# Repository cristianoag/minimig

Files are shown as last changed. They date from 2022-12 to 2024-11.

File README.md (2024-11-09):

# minimig
Recreating an Amiga500 with FPGA (consolidated repository)

The Minimig (short for "Mini Amiga") is a remarkable open-source hardware project designed to replicate the beloved Amiga 500 home computer, an iconic system from the late 1980s and early 1990s. Conceived by enthusiast Dennis van Weeren in 2005, the Minimig project began as a labor of love to faithfully recreate the Amiga’s unique architecture on an FPGA (Field Programmable Gate Array). Over time, it evolved with community contributions and open-source improvements, resulting in a versatile, accessible, and compact recreation of the original Amiga 500 that enthusiasts worldwide could use to relive and preserve classic Amiga software and games.

## Motivation
Recently I've been busy building a Minimig board. The Minimig is an FPGA-based implementation of the original Commodore Amiga 500 hardware.

This repository, together with the document available at http://www.theretrohacker.com/2022/12/20/an-fppga-based-amiga-the-minimig/ is my attempt to consolidate the very disperse documentation about the minimig and offer a concise guide if you want to build a board. Most of the websites that hosted files required are also offline currently. 

## License 

Open Hardware

This work is licensed under a [Creative Commons Attribution-NonCommercial-ShareAlike 4.0 International License](http://creativecommons.org/licenses/by-nc-sa/4.0/).

* If you remix, transform, or build upon the material, you must distribute your contributions under the same license as the original.
* You may not use the material for commercial purposes.
* You must give appropriate credit, provide a link to the license, and indicate if changes were made. You may do so in any reasonable manner, but not in any way that suggests the licensor endorses you or your use.

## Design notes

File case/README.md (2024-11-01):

# minimig cases

This folder stores multiple options for the minimig case. 

* 3D - Cases to be printed on 3D printers, also combined with acrylic top covers
* Acrylic - Full acrylic options to be cut on laser CNCs.

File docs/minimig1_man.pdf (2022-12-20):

## Minimig manual

Introduction
Well, you have built a Minimig board! Congratulations! This board should be considered purely experimental and is not a finished product. Therefore, some functions may not work and compatibility is not as good as a real Amiga. Also, be especially careful with ESD (electro static discharge). Although some protection is built into the Minimig, ESD can still kill it. This short manual will get you going with your Minimig. Please read it through carefully. I hope you will enjoy using the Minimig!

Configuring the flash card
To get the Minimig started, a FAT16-formatted MMC card is needed. A compatible card is supplied with the board. This card must contain at least the following files in the root directory:
- MINIMIG1.BIN
This is the FPGA core file needed to correctly configure the Spartan FPGA
- KICK.ROM
This is the kickstart rom file. All kickstart versions are supported but versions 1.2 or 1.3 are recommended for game compatibility.
Besides these two files, some ADF files are needed to let the Minimig do something more than displaying the Amiga boot screen. All files must be in the root directory. Sub directories are not supported.

Hooking up the Minimig
- Power
The Minimig must be supplied with a 5V STABILIZED POWER SUPPLY. Please use only the supplied power supply. A power supply with the wrong voltage or polarity will certainly damage the Minimig. Connect the power supply to the 2.1mm jack labelled “DC IN” at the back of the board. Centre pin is positive.
- Monitor
The Minimig has a standard 15pin VGA connector labelled “video” at the back of the board. Any monitor capable of displaying 50Hz display modes can be used. The 3-pin jumper next to this connector must be set to 31KHz (default).
- Audio
Standard PC-speakers can be connected to the 3.5mm jack labelled “audio” at the back of the board.
- Keyboard
A standard PS2 keyboard must be connected to the 6-pin mini connector labelled “keyboard” on the left-hand side of the board. A keyboard is necessary to operate the Minimig on-screen-display and to load ADF files. Some older keyboards may not work on the Minimig.
- Mouse
A standard PS2 mouse must be connected to the 6-pin mini connector labelled “mouse” on the left-hand side of the board. An optical mouse is supported.
- Joysticks
The Minimig has 2 9-pin joystick ports at the right-hand side of the board. Standard Amiga joysticks can be connected to these ports. The standard port for single-player games is the “JOY2” (upper) port. Do not use the 9-pin port at the back, that port is a serial port!

Powering up
Before applying power to Minimig, insert the MMC card. The card is only recognized at powerup. After applying power, the blue led (system power) will light up. The Minimig will search for the “minimig1.bin” and “kick.rom” files to boot the system. This may take a few moments. The loading of the kickstart rom will flash the screen in true retro-decrunching-style. This is normal behaviour. When the system has booted completely, the familiar Amiga boot screen will be shown.

On-screen-display
The Minimig is now ready for use and can be operated using 4 special keys on the PS2 keyboard and a so-called on-screen-display. The keys used are:
- F12
Just as with UAE, this key will invoke the on-screen-display. Pressing F12 again will hide the on-screen-display. The on-screendisplay can also be invoked by pressing the menu button at the front of the Minimig board.
- Page-up / Page-down
These keys are used to navigate the on-screen-display up and down.
- Home
This key is used to select an item on the on-screen-display.
The operating of the on-screen-display should be self-explanatory .

Resetting the Minimig
Just as with AOS 4.0, the Minimig is reset by holding down the control, left alt and right alt keys simultaneously. This will only reset the Amiga-side of the system. To reset the system completely or to reload the MMC-card, the power must be switched off/on.

More information
For more information, point your browser to http://home.hetnet.nl/~weeren001.

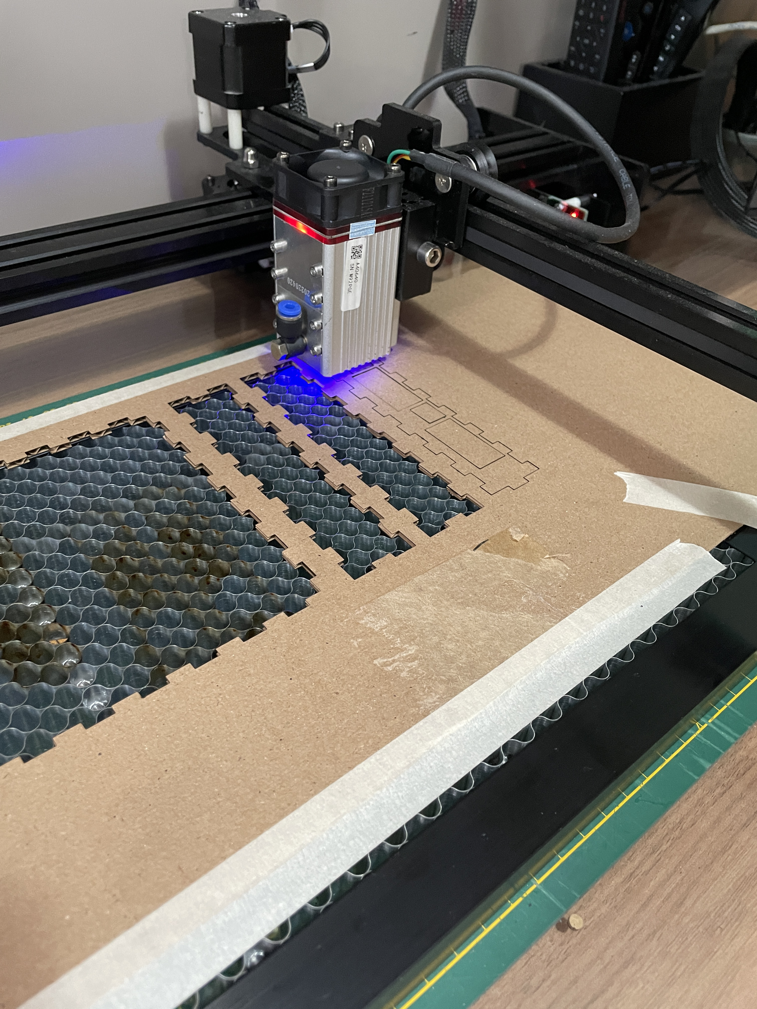
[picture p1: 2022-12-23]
pictures/20221222_165639893_iOS.jpg

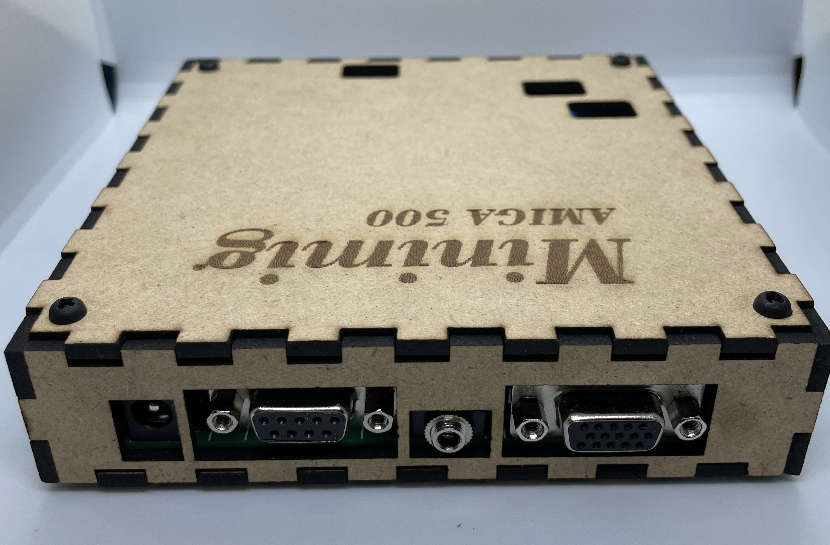
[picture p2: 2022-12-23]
pictures/20221222_223855441_iOS.jpg

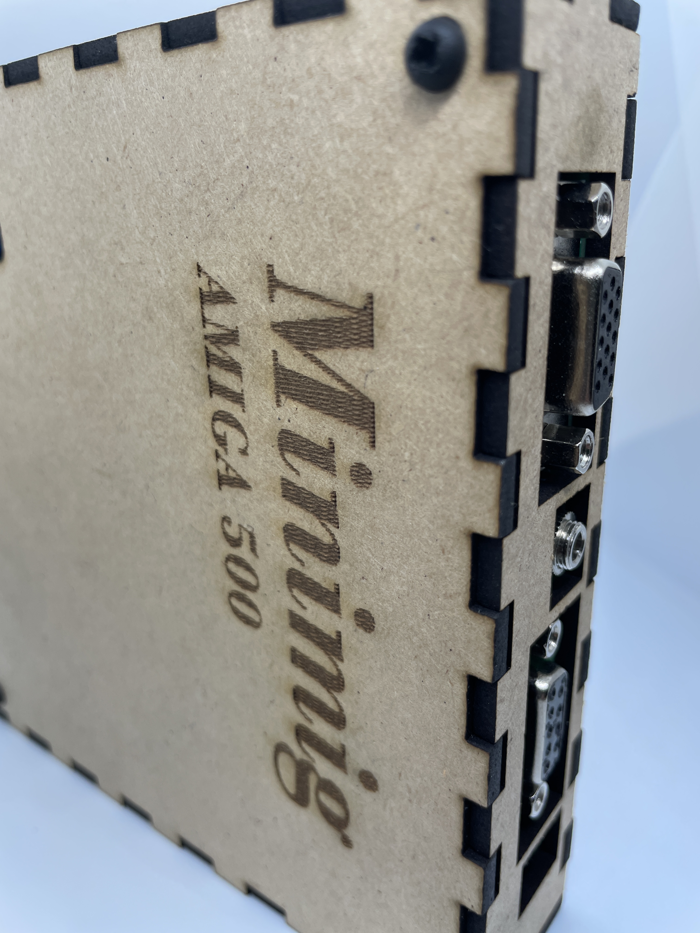
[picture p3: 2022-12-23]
pictures/20221222_223939605_iOS.jpg

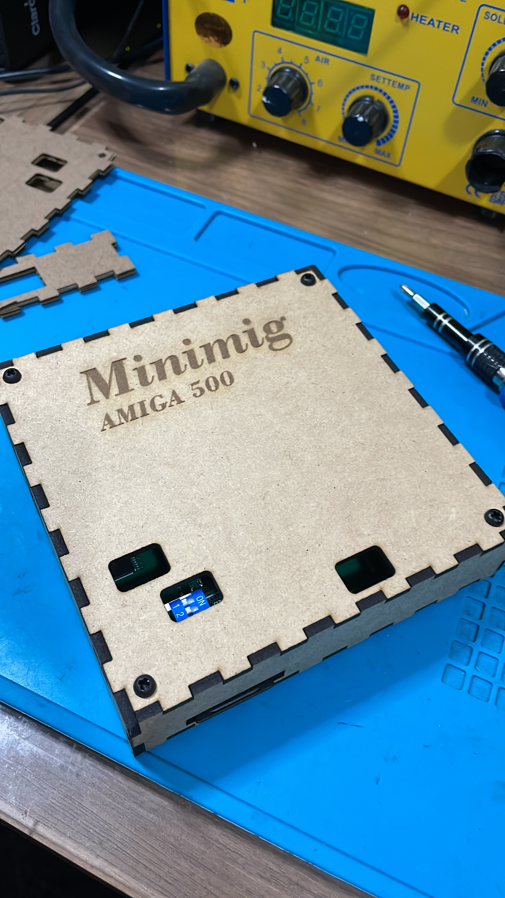
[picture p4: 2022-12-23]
pictures/20221222_202334973_iOS.jpg

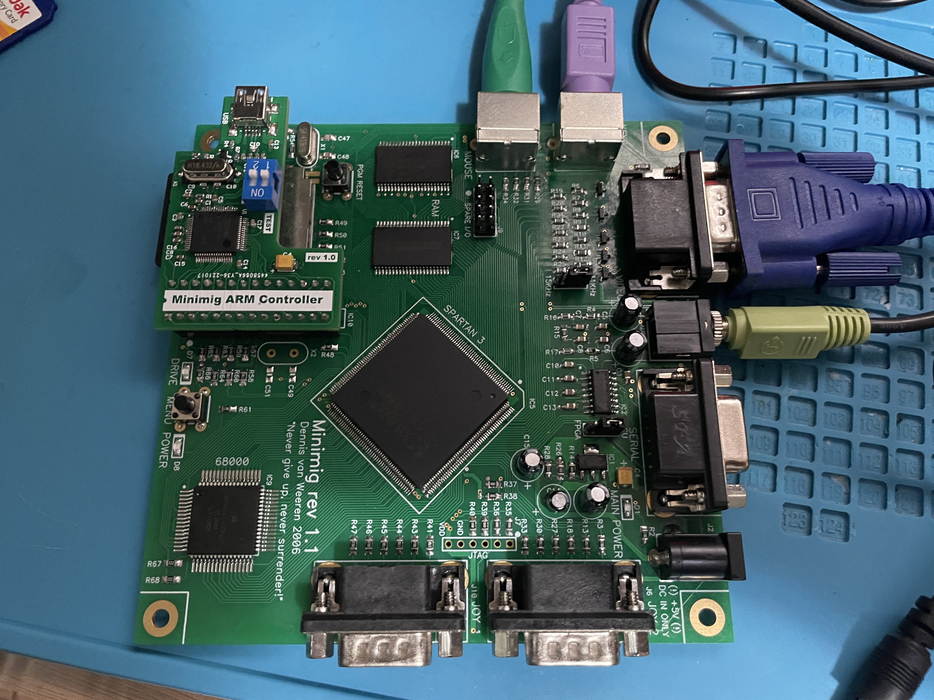
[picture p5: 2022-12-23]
pictures/20221220_040915800_iOS.jpg

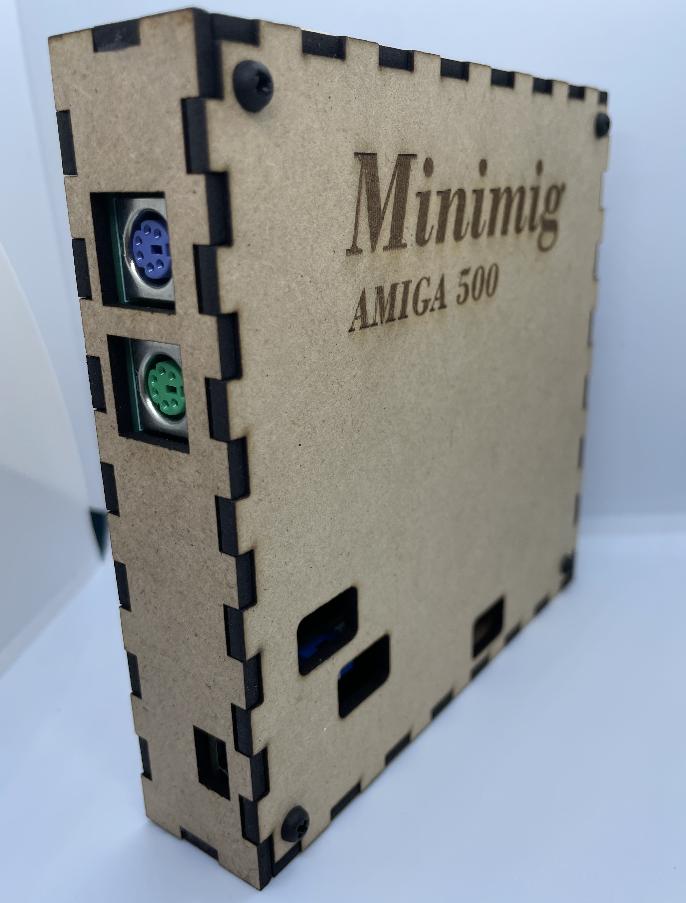
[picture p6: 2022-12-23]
pictures/20221222_223845031_iOS.jpg

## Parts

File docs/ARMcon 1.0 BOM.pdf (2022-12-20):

### Minimig ARM Controller 1.0 BOM

Value | Designator | Parameters | Manufacturer | Quantity
27R | R2, R3 | 0603 27R 0.1W 1% | | 2
1K5 | R1, R7 | 0603 1K5 0.1W 1% | | 2
10K | R6 | 0603 10K 0.1W 1% | | 1
100K | R5 | 0603 100K 0.1W 1% | | 1
1M | R4 | 0603 1M 0.1W 5% | | 1
10p | C9, C18 | 0603 10pF 50V 5% C0G | | 2
15p | C11, C12 | 0603 15pF 50V 5% C0G | | 2
33p | C10 | 0603 33pF 50V 5% C0G | | 1
1n | C1, C5, C8, C13 | 0603 1nF 50V 5% C0G | | 4
10n | C2 | 0603 10nF 50V 10% X7R | | 1
100n | C3, C14, C15, C16, C17 | 0603 100nF 16V 10% X7R | | 5
1u | C6, C7 | 0603 1uF 6.3V 10% X7R | | 2
10u/16V | C4 | SMD-B 10uF 10% 16V Tantalum | | 1
BC807-25 | Q1 | BC807-25 | NXP | 1
AT91SAM7S256-AU-001 | U1 | AT91SAM7S256-AU-001 | Atmel | 1
18.432MHz | X1 | HC49/SM 18.432 MHz | | 1
USB | CN1 | USB mini-B 5-pin SMD | | 1
28-pin header | U2 | 2 x 14-Pin Gold SIL Connector | preci-dip | 1

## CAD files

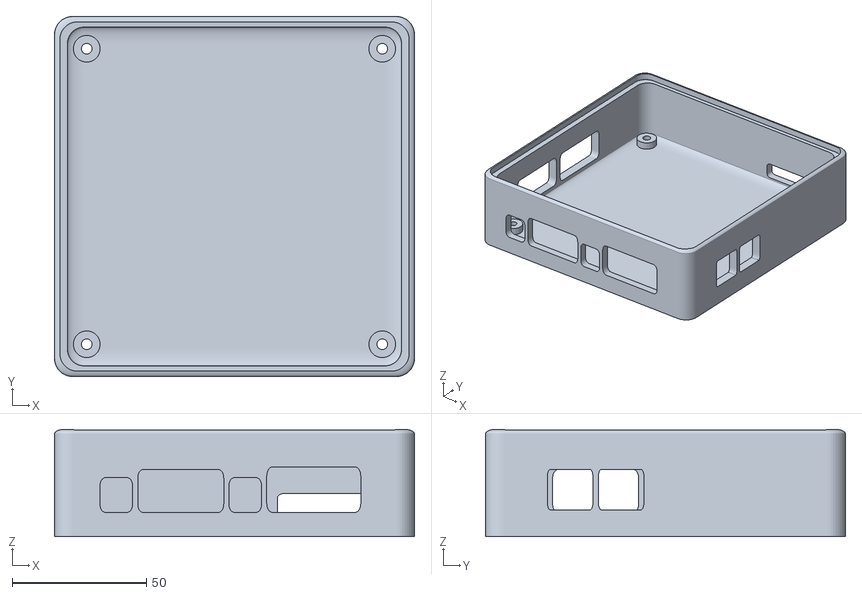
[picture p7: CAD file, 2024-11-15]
case/3D/Minimig Case [1.1].stl
134.0 x 134.0 x 39.9

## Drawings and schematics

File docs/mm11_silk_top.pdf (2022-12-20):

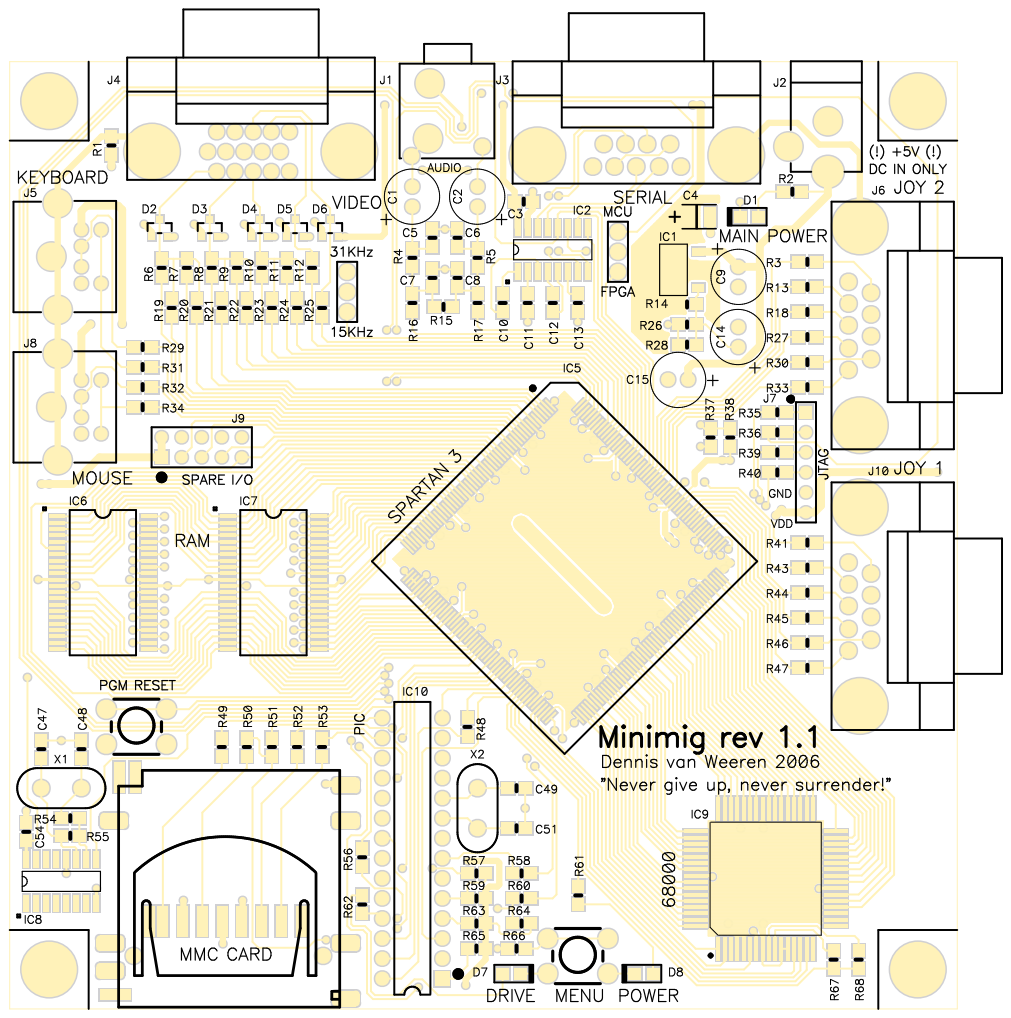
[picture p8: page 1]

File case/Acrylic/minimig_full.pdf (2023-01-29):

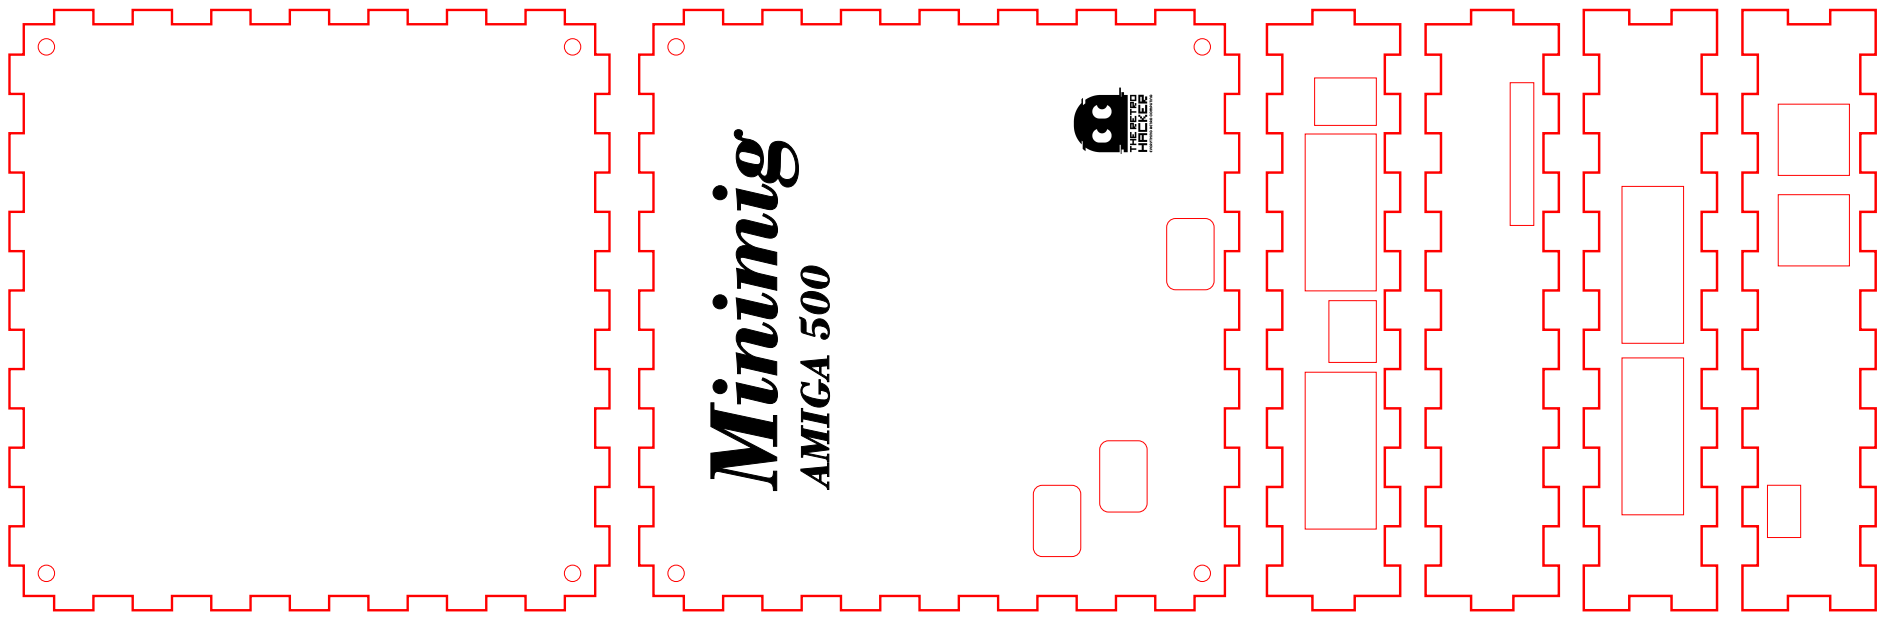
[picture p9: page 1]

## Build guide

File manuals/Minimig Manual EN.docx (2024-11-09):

# Minimig Manual – 1.0

## Introduction

The Minimig (short for "Mini Amiga") is a remarkable open-source hardware project designed to replicate the beloved Amiga 500 home computer, an iconic system from the late 1980s and early 1990s. Conceived by enthusiast Dennis van Weeren in 2005, the Minimig project began as a labor of love to faithfully recreate the Amiga’s unique architecture on an FPGA (Field Programmable Gate Array). Over time, it evolved with community contributions and open-source improvements, resulting in a versatile, accessible, and compact recreation of the original Amiga 500 that enthusiasts worldwide could use to relive and preserve classic Amiga software and games.

The Amiga series was revolutionary in its day, offering groundbreaking graphics, multitasking, and sound capabilities. However, as the years passed, finding original Amiga hardware became challenging. The Minimig emerged as a solution, delivering the authentic Amiga experience without the pitfalls of aging components.

The open-source design allows users and developers to continuously improve and expand its capabilities, making it both a practical choice and a nod to the pioneering spirit of the Amiga.

The Minimig you hold is designed for ease of use and portability, making it simple to run Amiga applications on modern hardware while capturing the nostalgia and ingenuity of the original machine. This manual will guide you through the setup and essential functions, helping you start your journey with the Minimig confidently and safely.

A Note on ESD (Electrostatic Discharge): Like any sensitive electronic equipment, the Minimig is susceptible to electrostatic discharge. While some ESD protection is built in, please take precautions to avoid direct static contact with the device.

This short manual will get you going with your Minimig, covering essential steps and tips to enhance your experience. Please read it carefully, and I hope you enjoy this modern take on a classic piece of computing history.

## Configuring the SD card

To get your Minimig started, you’ll need a FAT32-formatted SD card to store the essential files and software. A compatible SD card is provided with your Minimig, preformatted and ready to go. The root directory of this card must contain at least the following core files:

- MINIMIG1.BIN - This is the FPGA core file that allows the Minimig to initialize and configure the Spartan FPGA, essentially loading the hardware design that replicates the Amiga system. Without this file, the Minimig cannot properly start up.
- KICK.ROM - This is the Kickstart ROM file, which serves as the initial loading ROM for the Amiga environment. The Minimig supports various versions of the Kickstart ROM, including Kickstart 1.3, 2.0, and 3.1. Each version provides compatibility with different Amiga software, so feel free to experiment with the ROM version that best suits your needs. You can purchase the official/legal Amiga Kickstart at https://www.amigaforever.com/value/

In addition to these two core files, you’ll want to load some ADF (Amiga Disk Format) files onto the SD card. These files act as virtual disks containing games, software, or utilities in the original Amiga format. With ADF files on your SD card, the Minimig can go beyond displaying the basic Amiga boot screen and provide access to the full range of Amiga applications and games.

Since the Minimig you hold is equipped with an advanced ARM controller, the SD card supports folders, allowing you to organize your software collection neatly. You can create folders for different categories, such as “Games,” “Demos,” or “Utilities,” making it easier to locate and load specific applications.

Also observe the following tips when configuring your Minimig SD card:

1. File Compatibility: Ensure that the MINIMIG1.BIN and KICK.ROM files are compatible with your Minimig version. Regularly check the Minimig community for updates, as new FPGA core files and Kickstart compatibility enhancements are periodically released.
2. Organizing ADF Files: If your SD card contains a large collection of ADF files, using subfolders will improve navigation. The ARM controller on the Minimig allows you to browse and load ADF files from different folders through the on-screen menu, streamlining your experience.
3. Back Up Your SD Card: Before making significant changes, such as updating core files or adding many ADFs, it’s a good practice to back up the contents of your SD card. This ensures you can restore the system if needed.

With the SD card correctly set up, your Minimig is ready to launch into the Amiga experience. Make sure to insert the card into the Minimig’s SD slot securely before powering it on and enjoy exploring the digital heritage of the Amiga on your modern hardware.

## Hooking up the Minimig

To set up your Minimig, you’ll need to connect several peripherals to ensure proper operation. Follow these instructions carefully to prevent damage and get the best experience from your Minimig.

- Power - The Minimig requires a 5V 2A stabilized power supply to function safely. Only use the power supply provided with the Minimig, as power supplies with incorrect voltage or polarity may damage the system irreparably. Insert the power supply’s connector into the 2.1mm jack labeled “DC IN” at the back of the board, ensuring the center pin is positive.
- Monitor - The Minimig includes a standard 15-pin VGA connector labeled “VIDEO” at the back. You can use most modern monitors capable of displaying 50Hz video modes. Next to the VGA connector, you’ll find a 3-pin jumper that should be set to 31KHz (default), allowing compatibility with most VGA monitors. For compatibility with 15KHz monitors (such as certain vintage monitors), adjust the jumper to the 15KHz setting. Note that 15KHz monitors are uncommon, so be sure to check your monitor’s specifications if you intend to use one.
- Audio - To enjoy audio output, connect speakers or headphones to the 3.5mm audio jack labeled “AUDIO” at the back of the board. This provides stereo sound output, recreating the distinctive audio experience of the original Amiga system.
- Keyboard - A PS/2 keyboard is required for navigating the Minimig on-screen display (OSD) and loading ADF files. Connect the keyboard to the 6-pin mini-DIN connector labeled “KEYBOARD” on the left side of the board.
- Mouse - To interact with Amiga software effectively, a PS/2 mouse is recommended. The mouse connects to the 6-pin mini-DIN connector labeled “MOUSE” on the left side of the board. Optical mice are supported, though compatibility may vary depending on the model. The mouse is essential for Amiga software, which often relies heavily on pointer-based navigation.
- Joysticks - The Minimig supports two standard 9-pin Amiga joysticks, connectable via ports located on the right side of the board. The “JOY2” (upper) port is typically used as the primary joystick port for single-player games, while the “JOY1” (lower) port can be used for multiplayer games or other applications.

Note: Avoid connecting joysticks to the 9-pin port on the back of the board, as this is a serial port (female connector) and not intended for joystick use.

Following these set-up instructions will prepare your Minimig for operation, allowing you to enjoy a seamless experience as you explore Amiga software and games.

## Powering up

Before powering on your Minimig, insert the preconfigured SD card into the MMC slot. The Minimig can only recognize the SD card at startup, so ensure it’s inserted before applying power.

- Power On - Once the SD card is securely in place, connect the power supply to the Minimig. When powered on, the blue LED (system power indicator) will illuminate, signaling that the system is receiving power and initializing.
- File Loading - The Minimig will immediately begin searching for the SD card’s root directory for the MINIMIG1.BIN and KICK.ROM files, essential for the system to boot. The FPGA core (MINIMIG1.BIN) configures the FPGA hardware to run the Amiga hardware, while the KICK.ROM file loads the Amiga’s boot ROM.
- Kickstart ROM Initialization - As the Kickstart ROM loads, you may notice the screen flashing—a nostalgic “decrunching” effect reminiscent of the original Amiga boot process. This is normal behavior and indicates that the Minimig is initializing components and setting up the Amiga environment.
- Amiga Boot Screen - After the ROM has fully loaded, the familiar Amiga boot screen will appear. If ADF files are present on the SD card, you’ll be able to load them from the on-screen display (OSD) using your keyboard. At this stage, the Minimig is fully operational and ready to run Amiga software.

Once the boot process is complete, enjoy exploring your favorite Amiga applications and games, all faithfully recreated on your Minimig!

## Loading ADF Files Using the On-Screen Display (OSD)

With the Minimig booted up, you’re ready to load Amiga Disk Format (ADF) files—virtual disk images that allow you to run Amiga games and applications. The process of loading ADF files is managed through the on-screen display (OSD), which can be easily accessed using specific keys on your PS/2 keyboard.

The following keys are dedicated to navigating the OSD and loading ADF files:

- F12 Key - Press the F12 key to activate the on-screen display. This key works similarly to the UAE emulator, instantly bringing up the OSD. Pressing F12 again will close the OSD, returning you to the Amiga environment. Alternatively, you can also invoke the OSD by pressing the Menu button located at the front of the Minimig board.
- Page Up / Page Down Keys - Use the Page Up and Page Down keys to scroll through the options within the OSD. This allows you to browse folders, navigate specific ADF files, and access various settings on the Minimig.

Follow the steps below to load ADF files:

1. Access the OSD - Press F12 (or the Menu button on the Minimig) to bring up the OSD.
2. Navigate to the ADF File - Use Page Up and Page Down to scroll through the file list on the SD card. If you have organized your files into folders (e.g., “Games” or “Demos”), navigate to the desired folder.
3. Select an ADF File - Once you locate the ADF file you want to load, press space or enter key to select it. This will mount the ADF file as a virtual disk in the Amiga environment.
4. Start the Application - After selecting an ADF file, exit the OSD by pressing F12 again. The Minimig will automatically begin reading the selected ADF file, and the corresponding Amiga application or game should start shortly.

### Additional Tips

- Swapping Disks: For multi-disk games or applications, use the OSD to load additional ADF files as needed. Simply reopen the OSD, navigate to the next disk image, and select it with the Home key. Many games prompt you when to insert the next disk.
- Settings and Configurations: Besides loading ADF files, the OSD also allows you to configure various system settings, such as display modes and audio options. These can be adjusted through the OSD to customize your experience.

The on-screen display is intuitive, giving you quick and easy control over the Minimig functions. Once you’re comfortable with the OSD, loading and switching ADF files becomes a seamless part of the Amiga experience.

## Resetting the Minimig

Just as with AOS 4.0, the Minimig is reset by holding down the control, left alt and right alt keys simultaneously. This will only reset the Amiga-side of the system. To reset the system completely or to reload the MMC-card, the power must be switched off/on.

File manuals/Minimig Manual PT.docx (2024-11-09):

# Manual Minimig – 1.0

## Introdução

O Minimig (abreviação de "Mini Amiga") é um notável projeto de hardware de código aberto projetado para replicar o amado computador doméstico Amiga 500, um sistema icônico do final dos anos 1980 e início dos anos 1990.

Concebido pelo entusiasta Dennis van Weeren em 2005, o projeto Minimig começou como um trabalho de para recriar fielmente a arquitetura única do Amiga em um FPGA (Field Programmable Gate Array). Com o tempo, ele evoluiu com contribuições da comunidade e melhorias de código aberto, resultando em uma recriação versátil, acessível e compacta do Amiga 500 original que os entusiastas de todo o mundo poderiam usar para reviver e preservar o software e os jogos clássicos do Amiga.

A série Amiga foi revolucionária em sua época, oferecendo gráficos inovadores, multitarefa e recursos de som. No entanto, com o passar dos anos, encontrar o hardware original do Amiga tornou-se um desafio. O Minimig surgiu como uma solução, oferecendo a autêntica experiência do Amiga sem as armadilhas dos componentes antigos.

O design de código aberto permite que usuários e desenvolvedores melhorem e expandam continuamente seus recursos, tornando-o uma escolha prática e um aceno para o espírito pioneiro do Amiga.

O Minimig que você possui foi projetado para facilidade de uso e portabilidade, simplificando a execução de aplicativos Amiga em hardware moderno, capturando a nostalgia e a engenhosidade da máquina original. Este manual irá guiá-lo através da configuração e das funções essenciais, ajudando você a iniciar sua jornada com o Minimig com confiança e segurança.

Uma nota sobre ESD (descarga eletrostática): Como qualquer equipamento eletrônico sensível, o Minimig é suscetível a descargas eletrostáticas. Embora alguma proteção ESD esteja integrada, tome precauções para evitar o contato estático direto com o dispositivo.

Este pequeno manual irá ajudá-lo a usar seu Minimig, cobrindo etapas e dicas essenciais para aprimorar sua experiência. Por favor, leia-o com atenção e espero que você goste desta versão moderna de uma peça clássica da história da computação.

## Configurando o cartão SD

Para iniciar seu Minimig, você precisará de um cartão SD formatado em FAT32 para armazenar os arquivos e softwares essenciais. Um cartão SD compatível é fornecido com seu Minimig, pré-formatado e pronto para uso. O diretório raiz desta placa deve conter pelo menos os seguintes arquivos principais:

1. MINIMIG1. BIN - Este é o arquivo principal do FPGA que permite que o Minimig inicialize e configure o FPGA Spartan, essencialmente carregando o design de hardware que replica o sistema Amiga. Sem esse arquivo, o Minimig não pode iniciar corretamente.
2. KICK. ROM - Este é o arquivo ROM do Kickstart, que serve como ROM de carga inicial para o ambiente Amiga. O Minimig suporta várias versões da ROM do Kickstart, incluindo Kickstart 1.3, 2.0 e 3.1. Cada versão oferece compatibilidade com diferentes softwares Amiga, portanto, sinta-se à vontade para experimentar a versão da ROM que melhor se adapta às suas necessidades. Você pode comprar o Amiga Kickstart oficial/legal em https://www.amigaforever.com/value/

Além desses dois arquivos principais, você deve carregar alguns arquivos ADF (Amiga Disk Format) no cartão SD. Esses arquivos atuam como discos virtuais contendo jogos, software ou utilitários no formato original do Amiga. Com arquivos ADF em seu cartão SD, o Minimig pode ir além de exibir a tela básica de inicialização do Amiga e fornecer acesso a toda a gama de aplicativos e jogos do Amiga.

Como o Minimig que você possui está equipado com um controlador ARM avançado, o cartão SD suporta pastas, permitindo que você organize sua coleção de software de maneira organizada. Você pode criar pastas para diferentes categorias, como "Jogos", "Demos" ou "Utilitários", facilitando a localização e o carregamento de aplicativos específicos.

Observe também as seguintes dicas ao configurar seu cartão SD Minimig:

1. Compatibilidade de arquivos: Certifique-se de que o MINIMIG1. BIN e KICK.ROM são compatíveis com sua versão do Minimig. Verifique regularmente a comunidade Minimig para atualizações, pois novos arquivos principais do FPGA e aprimoramentos de compatibilidade do Kickstart são lançados periodicamente.
2. Organizando arquivos ADF: Se o seu cartão SD contiver uma grande coleção de arquivos ADF, o uso de subpastas melhorará a navegação. O controlador ARM no Minimig permite que você navegue e carregue arquivos ADF de diferentes pastas através do menu na tela, agilizando sua experiência.
3. Faça backup do seu cartão SD – Antes de fazer alterações significativas, como atualizar arquivos principais ou adicionar muitos ADFs, é uma boa prática fazer backup do conteúdo do seu cartão SD. Isso garante que você possa restaurar o sistema, se necessário.

Com o cartão SD configurado corretamente, seu Minimig está pronto para iniciar a experiência do Amiga. Certifique-se de inserir o cartão no slot SD do Minimig com segurança antes de ligá-lo e aproveite para explorar a herança digital do Amiga em seu hardware moderno.

## Conectando o Minimig

Para configurar seu Minimig, você precisará conectar vários periféricos para garantir o funcionamento adequado. Siga estas instruções cuidadosamente para evitar danos e obter a melhor experiência do seu Minimig.

1. Energia - O Minimig requer uma fonte de alimentação estabilizada de 5V 2A para funcionar com segurança. Utilize apenas a fonte de alimentação fornecida com o Minimig, pois fontes de alimentação com tensão ou polaridade incorretas podem danificar o sistema de forma irreparável. Insira o conector da fonte de alimentação no conector de 2.1 mm identificado como "DC IN" na parte traseira da placa, garantindo que o pino central seja positivo.
2. Monitor - O Minimig inclui um conector VGA padrão de 15 pinos rotulado como "VIDEO" na parte traseira. Você pode usar a maioria dos monitores modernos capazes de exibir modos de vídeo de 50Hz vertical. Ao lado do conector VGA, você encontrará um jumper de 3 pinos que deve ser definido como 31KHz (padrão), permitindo compatibilidade com a maioria dos monitores VGA. Para compatibilidade com monitores de 15KHz (como certos monitores antigos), ajuste o jumper para a configuração de 15KHz. Observe que os monitores de 15KHz são incomuns, portanto, verifique as especificações do seu monitor se pretende usar um.
3. Áudio - Para aproveitar a saída de áudio, conecte alto-falantes ou fones de ouvido ao conector de áudio de 3,5 mm identificado como "AUDIO" na parte traseira da placa. Isso fornece saída de som estéreo, recriando a experiência de áudio distinta do sistema Amiga original.
4. Teclado - Um teclado PS/2 é necessário para navegar na exibição na tela (OSD) do Minimig e carregar arquivos ADF. Conecte o teclado ao conector mini-DIN de 6 pinos identificado como "KEYBOARD" no lado esquerdo da placa.
5. Mouse - Para interagir com o software Amiga de forma eficaz, recomenda-se um mouse PS/2. O mouse se conecta ao conector mini-DIN de 6 pinos identificado como "MOUSE" no lado esquerdo da placa. Mouses ópticos são suportados, embora a compatibilidade possa variar dependendo do modelo. O mouse é essencial para o software Amiga, que geralmente depende muito da navegação baseada em ponteiros.
6. Joysticks - O Minimig suporta dois joysticks Amiga padrão de 9 pinos, conectáveis através de portas localizadas no lado direito da placa. A porta "JOY2" (superior) é normalmente usada como a porta principal do joystick para jogos single-player, enquanto a porta "JOY1" (inferior) pode ser usada para jogos multiplayer ou outros aplicativos.

Observação: evite conectar joysticks à porta de 9 pinos na parte traseira da placa, pois esta é uma porta serial (conector fêmea) e não se destina ao uso de joystick.

Seguir estas instruções de configuração preparará seu Minimig para operação, permitindo que você desfrute de uma experiência perfeita enquanto explora o software e os jogos do Amiga.

## Ligando o computador

Antes de ligar o Minimig, insira o cartão SD pré-configurado no slot MMC. O Minimig só pode reconhecer o cartão SD na inicialização, portanto, certifique-se de que ele esteja inserido antes de ligar a energia.

1. Ligar - Assim que o cartão SD estiver firmemente no lugar, conecte a fonte de alimentação ao Minimig. Quando ligado, o LED azul (indicador de energia do sistema) acenderá, sinalizando que o sistema está recebendo energia e inicializando.
2. Carregamento de arquivos - O Minimig começará imediatamente a procurar o diretório raiz do cartão SD para o MINIMIG1. BIN e KICK. ROM, essenciais para a inicialização do sistema. O núcleo FPGA (MINIMIG1. BIN) configura o hardware FPGA para executar o hardware Amiga, enquanto o KICK. ROM carrega a ROM de inicialização do Amiga.
3. Inicialização da ROM do Kickstart - À medida que a ROM do Kickstart é carregada, você pode notar a tela piscando - um efeito nostálgico de "decrunching" que lembra o processo de inicialização original do Amiga. Este é um comportamento normal e indica que o Minimig está inicializando componentes e configurando o ambiente do Amiga.
4. Tela de inicialização do Amiga - Depois que a ROM for totalmente carregada, a tela de inicialização familiar do Amiga aparecerá. Se os arquivos ADF estiverem presentes no cartão SD, você poderá carregá-los na exibição na tela (OSD) usando o teclado. Nesta fase, o Minimig está totalmente operacional e pronto para rodar o software Amiga.

Assim que o processo de inicialização estiver concluído, divirta-se explorando seus aplicativos e jogos favoritos do Amiga, todos fielmente recriados em seu Minimig!

## Carregando arquivos do ADF usando a exibição na tela (OSD)

Com o Minimig inicializado, você está pronto para carregar arquivos Amiga Disk Format (ADF) - imagens de disco virtual que permitem executar jogos e aplicativos do Amiga. O processo de carregamento de arquivos ADF é gerenciado por meio da exibição na tela (OSD), que pode ser facilmente acessada usando teclas específicas em seu teclado PS/2.

As seguintes teclas são dedicadas à navegação no OSD e ao carregamento de arquivos ADF:

1. Tecla F12 - Pressione a tecla F12 para ativar a exibição na tela. Essa chave funciona de forma semelhante ao emulador dos Emirados Árabes Unidos, ativando instantaneamente o OSD. Pressionar F12 novamente fechará o OSD, retornando ao ambiente Amiga. Como alternativa, você também pode invocar o OSD pressionando o botão Menu localizado na frente da placa Minimig.
2. Teclas Page Up / Page Down - Use as teclas Page Up e Page Down para percorrer as opções no OSD. Isso permite que você navegue por pastas, navegue por arquivos específicos do ADF e acesse várias configurações no Minimig.

Siga as etapas abaixo para carregar arquivos ADF:

1. Acesse o OSD - Pressione F12 (ou o botão Menu no Minimig) para abrir o OSD.
2. Navegue até o arquivo ADF - Use Page Up e Page Down para percorrer a lista de arquivos no cartão SD. Se você organizou seus arquivos em pastas (por exemplo, "Jogos" ou "Demos"), navegue até a pasta desejada.
3. Selecione um arquivo ADF - Depois de localizar o arquivo ADF que deseja carregar, pressione a tecla espaço ou enter para selecioná-lo. Isso montará o arquivo ADF como um disco virtual no ambiente Amiga.
4. Iniciar o aplicativo - Depois de selecionar um arquivo ADF, saia do OSD pressionando F12 novamente. O Minimig começará automaticamente a ler o arquivo ADF selecionado, e o aplicativo ou jogo Amiga correspondente deve começar em breve.

### Dicas adicionais

1. Troca de discos: Para jogos ou aplicativos com vários discos, use o OSD para carregar arquivos ADF adicionais conforme necessário. Basta reabrir o OSD, navegar até a próxima imagem de disco e selecioná-la com a tecla Home. Muitos jogos perguntam quando inserir o próximo disco.
2. Configurações e configurações: Além de carregar arquivos ADF, o OSD também permite definir várias configurações do sistema, como modos de exibição e opções de áudio. Eles podem ser ajustados por meio do OSD para personalizar sua experiência.

A exibição na tela é intuitiva, oferecendo controle rápido e fácil sobre as funções do Minimig. Quando estiver confortável com o OSD, carregar e alternar ficheiros ADF torna-se uma parte perfeita da experiência do Amiga.

## Reiniciando o Minimig

Assim como no AOS 4.0, o Minimig é redefinido mantendo pressionadas as teclas control, alt esquerda e alt direita simultaneamente. Isso apenas redefinirá o lado do Amiga do sistema. Para reiniciar o sistema completamente ou recarregar a placa MMC, a alimentação deve ser desligada/ligada.

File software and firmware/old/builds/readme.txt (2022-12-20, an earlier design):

Minimig firmware release 2008-08-04 by Jakub Bednarski.

    FPGA core version      : FYQ080729 
    68K bootloader version : BYQ080717
    PIC firmware version   : PYQ080725

Minimig copyright 2006-2008 by Dennis van Weeren.

How to install:

  - Remove any jumpers from SPARE I/O header.
  - Put "minimig1.bin" on your SD/MMC card.
  - Using Tiny Bootloader application program PIC's flash memory with "firmware.hex" file.
    If you are experiencing problems:
    1. Make sure you have bootloader programmed into your PIC.
    2. Take care about pressing the PGM/RESET button in appropriate moment.

Features:

    Scan doubler:

    - added vertical and horizontal interpolation (selectable independently for hires and lores)
    - semi-transparent osd window with active line highlight

    OSD menu:

    - added alternative control by joystick (up and down signals activated simultaneously invoke menu) 
    - configuration of: (configuration is stored in non-volatile memory inside the PIC)
      * memory options (512KB chip, 1MB chip, 512KB chip/512KB slow, 1MB chip/512KB slow)
      * video interpolation filters (vertical and horizontal interpolation for hires and lowres)
      * kickstart
        - both 256 and 512 KB non-encrypted kickstart files are supported (256KB kickstart takes 512KB of RAM)
        - stored filename is limited to 8 characters of letters A-Z and numbers 0-9
        - if stored kickstat file is missing default "kick.rom" file is loaded
        - kickstart file can be uploaded at run time without its name beeing stored in non-volatile memory (test purposes)
    - system reset from the OSD menu (no need for keyboard)

    New 68K bootloader (with video text mode).

    - displays information about firmware version and chipset configuration
    - allows to monitor the booting process 

    Chipset changes:

    - ECS blitter (Agnus is identified as ECS)
    - PAL/NTSC selection support (different FPGA core for initial settings)
    - modified blanking timing (better compatibility)
    - modified display dma engine (better compatibility)
    - modified sprite dma engine (better compatibility)
    - modified copper timing (better compatibility) 
    - modified floppy interface (better read and write support)
    - modified keyboard and mouse interface (better compatibility)

    Write support to ADF images:

      Since standard ADF images don't contain the MFM track data only write of sectors which conform to standard sector
    format is supported. It means that any attempt of non-standard sector write (i.e. long tracks) will be rejected
    and appropriate error message will be reported.
      Write protection status is read from the Read-Only file attribute. There is no option to change it on the Minimig.

    Action Replay III module:

      It was mandatory developing tool for finding bugs in current and future firmware implementations.
    Maybe someone will find it useful for other applications.
    It requires 256KB "AR3.ROM" file to be present on the SD/MMC card. The latest 3.17 rom version is only compatible
    with kickcstart 1.3 (34.5) and 2.04 (37.175). If the ROM file is missing the module is disabled.
    It can be disabled even though the ROM file is present on the flash card. To do so you need to press and hold 
    the "MENU" button on the Minimig while loading kickstart. It can only be done during initial booting after power-up.
    When enabled it takes one 512KB RAM bank so max. 1MB is available for chip and slow RAM.
    The "FREEZE" button is Ctrl+Break.

Thanks to:
 
     Dennis for his great Minimig
     Loriano for impressive enclosure 
     Darrin and Oscar for their involvement, ideas, support and help
     Toni for his indispensable help and logic analyzer (and WinUAE :-)

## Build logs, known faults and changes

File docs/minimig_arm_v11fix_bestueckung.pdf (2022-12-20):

Parts Minimig Rev1.1 (Edit.a1k) incl. Fixes | 13.02.2013
Count | ComponentName Value | RefDesignator | Comments
2 | RES_0805/1%, 33R | R50, R51, | new
3 | RES_0805/1%, 68R | R49, R52, R53, | new
9 | RES_0805/1%, 100R | R12, R14, R35, R36, R37, R38, R39,
| | R40, R42,
2 | RES_0805/1%, 180R | R25, R26,

### 25 RES_0805/1%, 270R

| | R2, R3, R13, R18, R27, R29, R30,
| | R31, R32, R33, R34, R41, R43, R44,
| | R45, R46, R47, R48, R56, R57, R58,
| | R60, R61, R62, R66,
7 | RES_0805/1%, 560R | R4, R5, R6, R8, R10, R16, R17,
4 | RES_0805/1%, 1K | R1, R19, R21, R23,
7 | RES_0805/1%, 2K2 | R7, R9, R11, R28, R54, R67, R68,
7 | RES_0805/1%, 4K7 | R20, R22, R24, R59, R63, R64, R65,
1 | RES_0805/1%, 1meg | R55,
1 | C_0805, 50V, NPO, 22pF | C47,
2 | C_0805, 50V, NPO, 47pF | C49, C51, | not needed
1 | C_0805, 50V, NPO, 100pF | C48,

### 22 C_0805, 50V, X7R, 10nF

| | C5, C6, C7, C8, C16, C18, C19, C21,
| | C22, C25, C28, C29, C30, C35, C36,
| | C39, C40, C43, C44, C46, C52, C55,

### 21 C_0805, 50V, X7R, 100nF

| | C3, C10, C11, C12, C13, C20, C23,
| | C24, C26, C31, C32, C33, C34, C38,
| | C41, C42, C45, C50, C53, C54, C56,
4 | CT_100uF/6.3V Bauform B | C4, C17, C27, C37,
1 | CE_DIA7.0MM/RA 22uF/16V/RM2.5 | C14,
4 | CE_DIA7.0MM/RA 100uF/16V/RM2.5 | C1, C2, C9, C15,
1 | LED_0805 BLUE | D1,
1 | LED_0805 GREEN | D7,
1 | LED_0805 RED | D8,
1 | XTAL_THT 4.433619MHz (HC49) | X1,
1 | XTAL_THT 20.000MHz (HC49) | X2, | not needed
5 | BAV99,215 | D2, D3, D4, D5, D6,
3 | LD1117STR (ADJ SOT-223) | IC1, IC3, IC4,
1 | 74HC4060 (SO-16 narrow) | IC8,
1 | SP3232EUCN (SOIC16-narrow) | IC2,
1 | XC3S400-4PQ208 | IC5,
2 | IS62WV51216BLL-55TLI | IC6, IC7, | 4 = 4MB
1 | MC68SEC000FU20 | IC9,
0 | PIC18LF252I/SP | IC10, | not needed
1 | 3.5MM_Audio_CON Lumberg KLBR4 | J1,
1 | DC_CON (Pin 2mm) | J2,
2 | PS2_CON (green+vio) | J5, J8,
3 | DSUBH_9M (EU) | J3, J6, J10,
1 | DSUBH_15F_HD | J4,
1 | SD_CARD | J11,
2 | Push button (Micro-Taster) | SCHK1, SCHK2,

### 1 Socket (PIC), 28pol, Präzision, RM7.5

1 | HEADER6MSIL 1x6 RM=2.54 | J7,
1 | HEADER10M (2x5 RM2.54) | J9,
2 | JUMPER3 (Header 1x3) | _1, _2,

### 2 JUMPER

155 Summe

Änderungen bereits oben eingepflegt !!

Fix: ARM Board - Fast SPI
2 | RES_0805/1%, 33R | R50, R51, | change
3 | RES_0805/1%, 68R | R49, R52, R53, | change
-1 | Soundfix Widerstand 1k entfernen | R15, | n.c.
| bei installiertem ARM-Board kann weg:
| I10, X2, C49, C51,
| Zusätzlich

### 1 Buzzer 1 Zuleitung 1 Schrumpfschlauch

1 | 47R Draht fuer Buzzer | wahlweise oder garnicht
1 | 100R Draht fuer Buzzer | wahlweise oder garnicht

### 5 Summe

| Minimig ARM Controller 1.0
Quantity Value | Designator
2 | 0603 27R (0.1W, 1%) | R2, R3,
2 | 0603 1K5 (0.1W, 1%) | R1, R7,
1 | 0603 10K (0.1W, 1%) | R6,
1 | 0603 100K (0.1W, 1%) | R5,
1 | 0603 1M (0.1W, 1%) | R4,
2 | 0603 10pF (50V 5% NPO) | C9, C18,
2 | 0603 15pF (50V 5% NPO) | C11, C12,
1 | 0603 33pF (50V 5% C0G) | C10,
4 | 0603 1nF (50V 5% X7R) | C1, C5, C8, C13,
1 | 0603 10nF (50V 5% X7R) | C2,
5 | 0603 100nF (16V 10% X7R) | C3, C14, C15, C16, C17,
2 | 0603 1uF (16V 10% X7R) | C6, C7,
1 | SMD-B 10uF 10% 10V Tantalum | C4,
1 | BC807-25 (NXP) | Q1,
1 | AT91SAM7S256-AU-001 (Atmel) | U1,
1 | HC49/SM 18.432 MHz SMD | X1,
1 | USB mini-B 5-pin SMD | CN1,
2 | 14-pin (2x7narrow) IC-Steck-Adapter | U2,
1 2fach IC-DIP-Switch

### 32 Summe

192 | Teile | total
| NewAmigaUser-FAQ mit Fixes
http://www.a1k.org/forum/showthread.php?t=30671

NewAmigaUser: Minimig und ARM Controller Zusammenbau http://www.a1k.org/forum/showthread.php?t=35526

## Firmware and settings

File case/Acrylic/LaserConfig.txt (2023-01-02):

cardboard 3mm
cut 150 speed 230 power
engrave 2500 speed 500 power


mdf 3mm
cut 120 speed 1000 power
engrave 2500 speed 800 power

black acrylic 3mm
cut 120 speed 1000 power

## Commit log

2022-12-23 Including pictures and the case project
    [LaserConfig.txt]
2023-01-02 rest of the case plans
    [LaserConfig.txt]
2023-01-29 A3 sheet with the full case to print
2024-11-01 new case options and firmware update
    [LaserConfig.txt, Minimig Case.stl]
2024-11-15 3D case update
    [Minimig Case [1.1].stl, Minimig Case.stl]
